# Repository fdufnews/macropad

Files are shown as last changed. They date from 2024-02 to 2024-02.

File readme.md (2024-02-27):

# MacroPad

## How it started from
As a left-hander, using keyboard shortcuts is usually problematic. Many of them have to use the left hand so I have to let go of the mouse, type the key combination, pick up the mouse again, or twist my fingers to type the key combination with the right hand.  
After some research on the Internet I found the [DuckyMacroPad](https://github.com/aarnas/pico-circuit-python/tree/main/Projects/DuckyMacroPad) of a simple combination of hardware and software. 

I quickly tested it and found some limitations to what I wanted. So I forked the repository and started my own version of Macropad. Added support for a matrix keyboard and some keywords to make the scripts more versatile.

## Description of what I wanted
- a macropad with between 9 and 12 keys (not too much keys as I wanted the keypad to stay atop my keyboard)
- progammed in Python
- no daemon on the computer
- support of different keymaps (I have a desktop with a french keyboard and a laptop with a US keyboard).
- programmable macros with support for some software and easy modification of them without a specific tool.

## What I ended with
 A macropad with:
 
- Raspberry Pi Pico, running CircuitPython (as CircuitPython supports USB HID and make the Pico be viewed as an externel disk)
- 12 buttons, 9 seems a bit limited
- 1 rotary encoder, this adds some pleasant tricks like undo/redo at the turn of a button
- a 280 x 240 TFT color display, to show key affectation

## Pin allocation on the Raspberry Pi Pico
```
|        |       |    |     ┏━━━━━┓     |    |          |          |
|        |       |    |┏━━━━┫     ┣━━━━┓|    |          |          |
|        | GP0   | 1  |┃◎   ┗━━━━━┛   ◎┃| 40 |VBUS      |          |
|        | GP1   | 2  |┃◎ ▩           ◎┃| 39 |VSYS      |          |
|        | Ground| 3  |┃▣ └─GP25      ▣┃| 38 |Ground    |          |
| L1     | GP2   | 4  |┃◎  ▒▒▒        ◎┃| 37 |3v3 En    |          |
| L2     | GP3   | 5  |┃◎  ▒▒▒        ◎┃| 36 |3v3 Out   |          |
| L3     | GP4   | 6  |┃◎             ◎┃| 35 |ADC VRef  |          |
| R1     | GP5   | 7  |┃◎             ◎┃| 34 |GP28 / A2 |          |
|        | Ground| 8  |┃▣             ▣┃| 33 |ADC Ground|          |
|        | GP6   | 9  |┃◎   ▓▓▓▓▓▓▓   ◎┃| 32 |GP27 / A1 |          |
| ROT1A  | GP7   | 10 |┃◎   ▓▓▓▓▓▓▓   ◎┃| 31 |GP26 / A0 |          |
| ROT1B  | GP8   | 11 |┃◎   ▓▓▓▓▓▓▓   ◎┃| 30 |run       |          |
| ROT1S  | GP9   | 12 |┃◎   ▓▓▓▓▓▓▓   ◎┃| 29 |GP22      | TFT_BLK  |
|        | Ground| 13 |┃▣             ▣┃| 28 |Ground    |          |
| C1     | GP10  | 14 |┃◎             ◎┃| 27 |GP21      | TFT_CS   |
| C2     | GP11  | 15 |┃◎             ◎┃| 26 |GP20      | TFT_MISO |
| C3     | GP12  | 16 |┃◎             ◎┃| 25 |GP19      | NU       |
| C4     | GP13  | 17 |┃◎             ◎┃| 24 |GP18      | TFT_SCK  |
|        | Ground| 18 |┃▣             ▣┃| 23 |Ground    |          |
| R2     | GP14  | 19 |┃◎             ◎┃| 22 |GP17      | TFT_CD   |
| R3     | GP15  | 20 |┃◎    ◎ ▣ ◎    ◎┃| 21 |GP16      | TFT_RS   |
|        |       |    |┗━━━━━━━━━━━━━━━┛|    |          |          |
```
R1-3 are reserved for future use. They are parts of the 2 connectors that are connecting the keyboard to the main board

The full [schematic is here](hardware/MacroPad.pdf)

## View of the Macropad
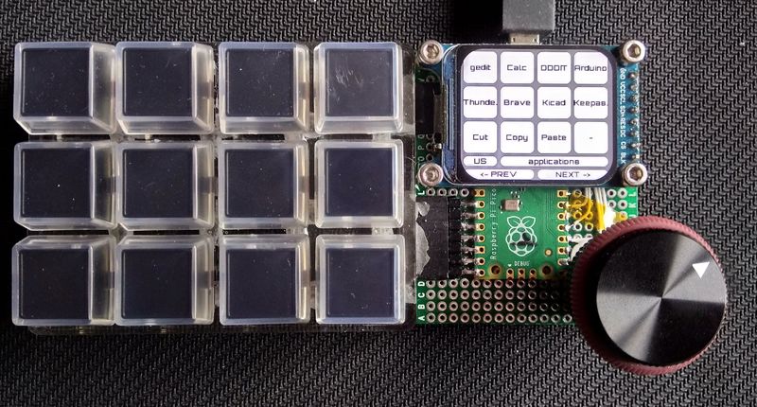
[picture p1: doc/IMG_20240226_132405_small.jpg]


## How it works
The Macropad embeds its own documentation.
If plugged with the rotary encoder pushed, the Macropad also shows itself as an external thumb drive where a readme.md with the documentation can be found.
It is [here too](software/pico_fs/readme.md)

## Software
The full source code with comments is [here](software/code_full.py)
The [pico_fs](pico_fs) directory contains all the necessary files to make a functionnal Macropad: a stripped code, the drivers, the fonts, some scripts.  
Once the Pico is programmed with CircuitPython, all files in pico_fs shall be copyed on the CIRCUITPY drive.

## Todo list
### Easy
[x] Add management of key colors in the settings.toml file  
[x] add a keyword for the script to switch the layer. Example, selecting Gedit in the *applications* layer launches Gedit and switches to *Edition* layer  
### Difficult
[] Look if it is possible to use either of icons or text in the keys without exploding memory and making software slower (Difficult as it can be very memory hungry).  
[] Search a way to place multi lines of text in the keys. It is very boring to be limited to 5 or 6 caracters (difficult as it all depends on the buttons library).

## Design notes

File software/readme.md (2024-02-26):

- code_full is the software with all the comments  
- stripcomments.sh is used to delete all the comments and generate a smaller file that is copied in pico_fs.  
- The content of pico_fs can be uploaded as is on the board. It contains a copy of the readme.md file so the Macropad embeds its own documentation

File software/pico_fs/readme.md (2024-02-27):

# MacroPad

## What it is
 A macropad with:
 
- a Raspberry Pi Pico, running CircuitPython (as CircuitPython supports USB HID and make the Pico be viewed as an externel disk)
- 12 buttons, 9 seems a bit limited
- 1 rotary encoder, this adds some pleasant tricks like undo/redo at the turn of a button
- a 280 x 240 TFT color display, to show key affectation

## View of the Macropad


## Detail of the display

```
╭───╮ ╭───╮ ╭───╮ ╭───╮
│ 0 │ │ 1 │ │ 2 │ │ 3 │ 
╰───╯ ╰───╯ ╰───╯ ╰───╯ 
╭───╮ ╭───╮ ╭───╮ ╭───╮
│ 4 │ │ 5 │ │ 6 │ │ 7 │ 
╰───╯ ╰───╯ ╰───╯ ╰───╯ 
╭───╮ ╭───╮ ╭───╮ ╭───╮
│ 8 │ │ 9 │ │ 10│ │ 11│ 
╰───╯ ╰───╯ ╰───╯ ╰───╯ 
LANG     Layer name
<- PREV         NEXT ->

```
| Item | Comment |
|:---|:---|
| 0..11 | The labels of the keys as extracted from the scripts|
| LANG | Displays the current selected language|
|Layer name | Shows the name of the current layer|
|PREV/NEXT | There is currently no way to dynamically change the labels for the rotary encoder.|

## Consumption
The Macropad consume 60mA with backlight at full power

## Syntax of the scripts
The scripts directory is where the script are saved.  
There is a directory for each layer which name is used as the layer's name that is displayed on the screen. Name can be any one supported by the filesystem. There is a scan of the scripts each time language is changed so if layers are added while the Macropad is running they can be recognized by simply switching the language.  
In each layer, there is one file for each key. 12 keys + rotary encoder CW and CCW fake buttons. Files are named 0 to 13.  
Scripts are using some keywords
### Keywords
#### Currently supported keywords
- `#` some text 
to add a comment.  
Ignored when playing the scripts
- LABEL xxxxxx  
Define the label that is printed on the key. SHALL BE THE 1rst LINE OF THE SCRIPT.  
Depending on the font's size, the label can be truncated if too long.  
If no LABEL is found on the first line of the script, the label will be the key number.  
Ignored when playing the scripts
- DELAY xxxx  
define a delay of xxxx mS
- STRING xxxxxxxx  
the string xxxxxxxx is sent to the host

- DEFAULT_DELAY or DEFAULTDELAY xxxx  
sets the default delay between keys when they are sent

- REPEAT xxx  
repeat the previous line xxx times

- KEY_SEL / KEY_UNSEL  
Set the key selected or not, when selected the color is inverted. Can be used for indication of the state of a latched key (see examples)

- FLAG_SET / FLAG_RESET xxxxx  
Set/reset flag named xxxx. Will be used with IF statements

- LAYER layerName  
switch the layer to layerName if it exists. Beware that a layer name is a directory name and can be case sensitive on some OS.

- IF / IF_NOT  xxxx  
Test if flag xxxx is set or not

- ELSE  
else statement, to be used with IF

- ENDIF  
close an IF or IF ... ELSE statement.

### Keycodes
Apart from the previous keywords a line can contain keycodes like
WINDOWS, GUI, APP, MENU, SHIFT, ALT, CONTROL, DOWNARROW, LEFTARROW, A, B, F1,....
So, to send ctrl+c one shall put `CONTROL C` on a single line
The list of the keywords can be find in the keycode libraries used

### Examples
#### Example 1
A macro to open gedit editor can be build like this
```text
LABEL Gedit
#  open launcher
ALT F2
#  wait for the popup to open
DELAY 200
#  GEDIT
STRING gedit
ENTER
```
#### Example 2
A macro to open the find dialog in gedit.  
When clicked for the first time: send CTRL+F to open the find dialog, sets the key as selected and sets a flag.  
If the flag is already set send escape to close the dialog, unselect the key, reset the flag. 
While the flag is set, it can be used to change the way the rotary encoder works and uses it to jump to next or previous words.    

```text
# Make a bistable key
IF_NOT CTRLF 
# open find dialog
CONTROL F
KEY_SEL
FLAG_SET CTRLF
ELSE
# close find dialog
ESC
KEY_UNSEL
FLAG_RESET CTRLF
ENDIF
```
Script for the CCW direction of the rotary encoder
```
LABEL NEXT ->
# if CTRLF active rotary encoder will send CTRL g (previous occurrence of word in search)
IF CTRLF
CONTROL SHIFT g
# if CTRLF not active will send CTRL z wich is undo
ELSE
CONTROL z
ENDIF
```
Keys are numbered from top left to bottom right

```
╭───╮ ╭───╮ ╭───╮ ╭───╮
│ 0 │ │ 1 │ │ 2 │ │ 3 │ 
╰───╯ ╰───╯ ╰───╯ ╰───╯ 
╭───╮ ╭───╮ ╭───╮ ╭───╮
│ 4 │ │ 5 │ │ 6 │ │ 7 │ 
╰───╯ ╰───╯ ╰───╯ ╰───╯      <--   -->
╭───╮ ╭───╮ ╭───╮ ╭───╮     ╭───╮ ╭───╮
│ 8 │ │ 9 │ │ 10│ │ 11│     │ 13│ │ 12│
╰───╯ ╰───╯ ╰───╯ ╰───╯     ╰───╯ ╰───╯
```
A macro can have any number of line. Beware, the longer the slower.  
A line can contain keywords and/or keycodes  

## Encoder pushbutton
A short push on the encoder pushbutton switches to the next layer. When reaching the last layer the count rolls back to 0.  
A long push switches the current language.

## Default configuration
The *settings.toml* file at the root of the file system can be used to specify the default language and layer.  
Settings are key pairs. One key name followed by an equal sign followed by the value in double quotes.  
Example  
```
lang="FR"
default="applications"
font="orbitron_black14.pcf"
style="ROUNDRECT"
background="ORANGE"
fill_color="0xffffff"
outline_color="GREEN"
label_color="DARKBLUE"
selected_fill="DARKGRAY"
selected_outline="RED"
selected_label="RED"
```

| key | Comment |
| :--- | :---|
|lang |Language for the keyboard either of "FR" or "US" others can be added in code.py|
|default |Layer opened by default, if missing the first layer, in alphabetical order, will be selected|
|font |Font used to display the label, if missing terminalio.FONT will be used. Fonts are supposed to be in the fonts directory. Only the filename is necessary, not a full path|
|style |Style of the buttons one of RECT, ROUNDRECT, SHADOWRECT, SHADOWROUNDRECT can not be used. If missing ROUNDRECT is used|
|background |Color of the background of the display. see color after the table|
|fill_color |Fill color of the buttons|
|outline_color |Color of the outline of the buttons|
|label_color |Color of the labels|
|selected_fill |Fill color when button is selected|
|selected_outline |Color of the outline of the buttons when selected|
|selected_label |Color of the labels when buttons are selected|

__color__: color can be a color name from the following list or an integer number either in decimal or in hexadecimal. Numbers shall be quoted too  
There is list of predefined colors in the code.  
BLACK = 0x000000  
LIGHTORANGE = 0xFF8800  
ORANGE = 0xe66100  
BROWN = 0x3F2200  
WHITE = 0xFFFFFF  
GRAY = 0x888888  
LIGHTGRAY = 0xdddddd  
DARKGRAY = 0x5e5c64  
LIGHTGREEN = 0x00FF44  
GREEN = 0x289525  
DARKGREEN = 0x19571d  
RED = 0xFF0000  
PURPLE = 0x9141ac  
YELLOW = 0xf8e45c  
LAVENDER = 0x99c1f1  
BLUE = 0x1c71d8  
DARKBLUE = 0x2e4480  
LIGHTBLUE = 0x62a0ea  

## USB drive
The Macropad can be viewed as an USB drive or not.  
By default, the USB drive mode is not active.  
To make this mode active, the user shall plug in the Macropad while keeping the rotary encoder pushed. The USB drive will then be active and the drive will be presented as CIRCUITPY. User can then modify, copy or edit any file. The drive is 1MB with around 150kB used by the default configuration so don't try to use it as a 'real thumb drive'.  

It is boot.py that tests if the rotary encoder is pushed at power on and activate or not the USB drive.
## Directory tree
Here is a picture of the directory tree on the CIRCUITPY disk.  
```text
root
     |
     |\_fonts
     |
     |\_lib
     |
     |\_scripts
     |         |
     |         |
     |         |\_layer0
     |         |        |\_0
     |         |        |\_1
     |         |        |\_..
     |         |        |\_12
     |         |        |\_13
     |         |
     |         |\_layer1
     |         |        |\_0
     |         |        |\_..
     |         |        |\_13
     |         |
     |
     |\_boot.py
     |\_code.py
     |\readme.md
     |\settings.toml
```

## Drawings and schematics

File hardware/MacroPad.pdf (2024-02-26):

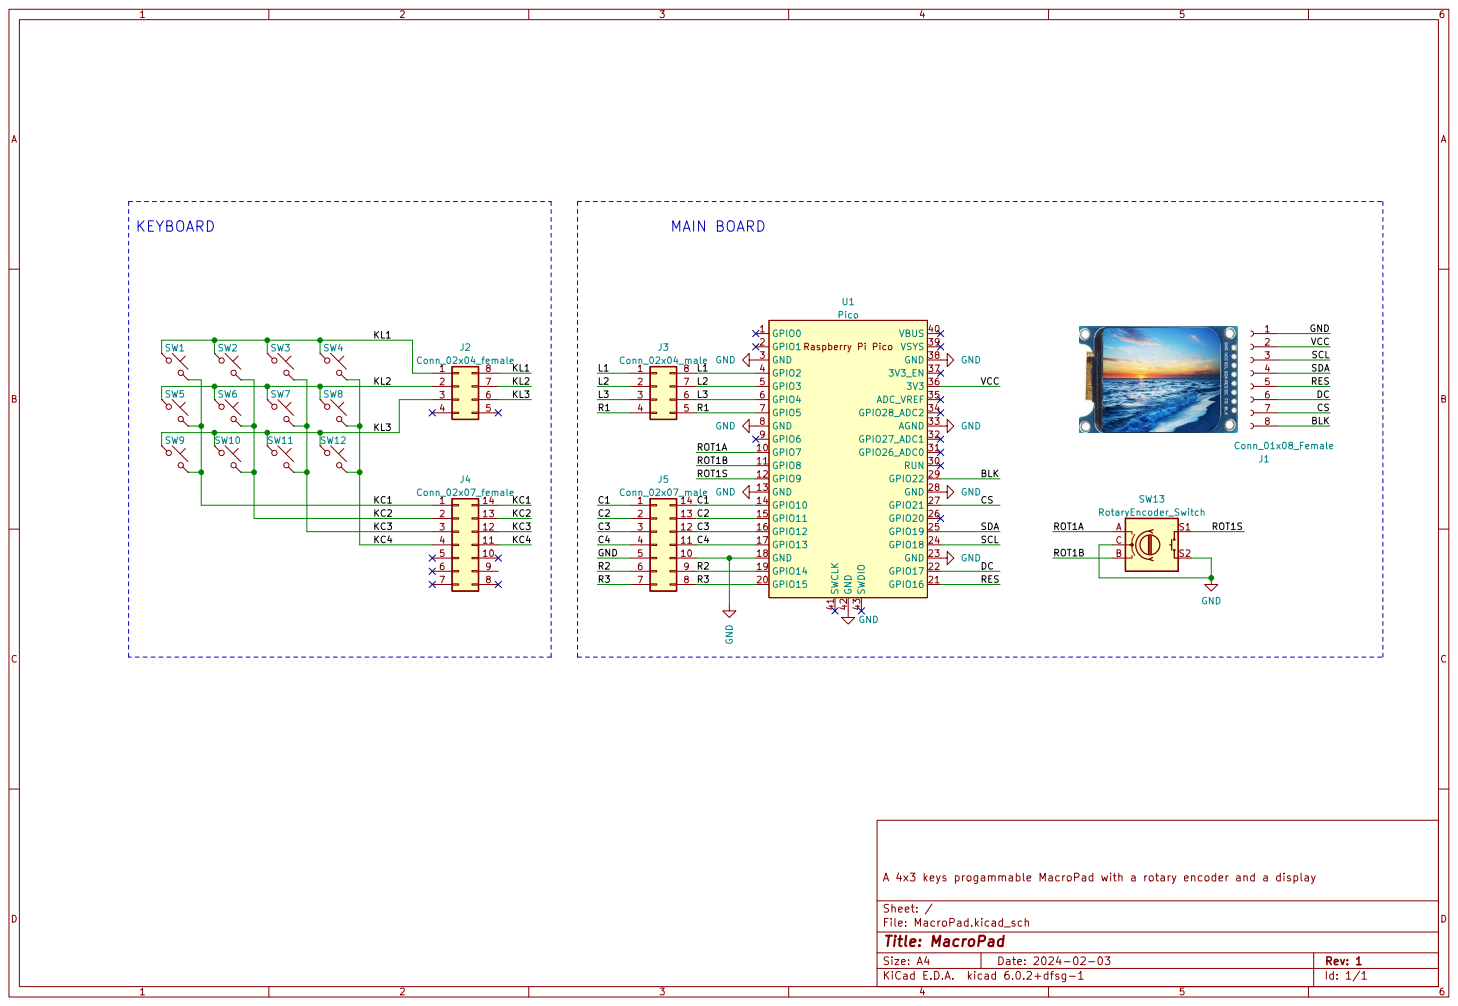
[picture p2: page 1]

File: MacroPad.kicad_sch Sheet: / A 4x3 keys progammable MacroPad with a rotary encoder and a display

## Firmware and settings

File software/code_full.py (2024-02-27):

import time
import board
import digitalio
import usb_hid
from adafruit_hid.keyboard import Keyboard
from adafruit_hid.keyboard_layout_us import KeyboardLayoutUS
from adafruit_hid.keycode import Keycode as KeycodeUS
from keyboard_layout_win_fr import KeyboardLayout as KeyboardLayoutFR
from keycode_win_fr import Keycode as KeycodeFR
import rotaryio
from fakeButton import *
import adafruit_matrixkeypad
import os

import busio
import terminalio
import displayio
from adafruit_display_text.label import Label
from adafruit_bitmap_font import bitmap_font
from adafruit_display_shapes.rect import Rect
from adafruit_button import Button
import gc

try:
    from fourwire import FourWire
except ImportError:
    from displayio import FourWire
from adafruit_st7789 import ST7789

version = '1.2'

tabLang = [['FR','US'],
            [KeyboardLayoutFR, KeyboardLayoutUS],
            [KeycodeFR, KeycodeUS]
]

langCount = len(tabLang[0])
langIndex = 0
language = ''
layerList = []
layerCount = 0
layerIndex = 0
layer = ''

labels = []

# declare a keyboard device with default FR layout
keyboard = Keyboard(usb_hid.devices)
layout = KeyboardLayoutFR(keyboard)
Keycode = KeycodeFR

# Extended 3x4 matrix keypad
cols = [digitalio.DigitalInOut(x) for x in (board.GP10, board.GP11, board.GP12, board.GP13)]
rows = [digitalio.DigitalInOut(x) for x in (board.GP2, board.GP3, board.GP4)]
# keys shall be numbered, starting from 0 and increasing 1 by 1, order is not important
keys = (
    (0, 1,  2,  3), 
    (4, 5,  6,  7), 
    (8, 9, 10, 11)
    )

keypad = adafruit_matrixkeypad.Matrix_Keypad(rows, cols, keys)

# compute size of keys array
nb_keys = len(keys) * len(keys[0])

# rotary encoder definition
encoder_A = board.GP7
encoder_B = board.GP8
encoder_PUSH = board.GP9
delayLongPush = 1000000000

# compute index of fake buttons using size of keys array so they are always registered after the key matrix 
coder_cw = nb_keys
coder_ccw = coder_cw + 1
# and add 2 elements to the length to manage rotary encoder CW and CCW
nb_keys += 2

# time for debounce keys in 10ms steps
time_debounce = 25

# dico containing the flags set in the scripts
dico_flags = {}
in_if = False
in_else = False
wait_else_or_endif = False
wait_endif = False

# Settings
BUTTON_WIDTH = 64
BUTTON_HEIGHT = 60
BUTTON_MARGIN = 4
STATUS_HEIGHT = 20

# Some colors
BLACK = 0x000000
LIGHTORANGE = 0xFF8800
ORANGE = 0xe66100
BROWN = 0x3F2200
WHITE = 0xFFFFFF
GRAY = 0x888888
LIGHTGRAY = 0xdddddd
DARKGRAY = 0x5e5c64
LIGHTGREEN = 0x00FF44
GREEN = 0x289525
DARKGREEN = 0x19571d
RED = 0xFF0000
PURPLE = 0x9141ac
YELLOW = 0xf8e45c
LAVENDER = 0x99c1f1
BLUE = 0x1c71d8
DARKBLUE = 0x2e4480
LIGHTBLUE = 0x62a0ea

style=Button.ROUNDRECT
background=GRAY
fill_col=WHITE
outline_col=BLACK
label_col=BLACK
sel_fill=BLACK
sel_outline=WHITE
sel_label=WHITE

font = terminalio.FONT

def button_grid(row, col):
    return(BUTTON_MARGIN * (row + 1) + BUTTON_WIDTH * row,
        BUTTON_MARGIN * (col + 1) + BUTTON_HEIGHT * col)

def add_button(col, row, label, width, fill_color, outline_color, label_color, selected_fill, selected_outline, selected_label, style):
    pos = button_grid(row, col)
    new_button = Button(x = pos[0], y = pos[1],
                    width=BUTTON_WIDTH * width + BUTTON_MARGIN * (width - 1),
                    height = BUTTON_HEIGHT, label=label, label_font=font,
                    label_color=label_color, fill_color=fill_color,
                    outline_color=outline_color, selected_fill=selected_fill,
                    selected_outline=selected_outline, selected_label=selected_label,
style=style)
    buttons.append(new_button)
    return new_button
    
def find_button(label):
    result = None
    for _, btn in enumerate(buttons):
        if btn.label == label:
            result = btn
    return result


def convertLine(line):
    newline = []
#    print(line)
    # loop on each key - the filter removes empty values
    for key in filter(None, line.split(" ")):
        key = key.upper()
        if hasattr(Keycode, key):
            # if it's in the Keycode module, use it (allows any valid keycode)
            newline.append(getattr(Keycode, key))
        else:
            # if it's not a known key name, show the error for diagnosis
#            print(f"Unknown key: <{key}>")
            pass
#    print(newline)
    return newline

def runScriptLine(line):
    for k in line:
        keyboard.press(k)
    keyboard.release_all()

def sendString(line):
    layout.write(line)

def switchKey(keynum, state):   
    buttons[keynum].selected = True if state == 'KEY_SEL' else False

def parseLine(filename, line):
    global defaultDelay
    global dico_flags
    global in_if
    global in_else
    global wait_else_or_endif
    global wait_endif
    global layerIndex
    global layer
    
# *******************************************************************
# Added keywords
# *******************************************************************
    if line[0:5] == "LABEL":
        # ignore LABEL statement
        pass
    elif(line[0:3] == "#"):
        # ignore script comments
        pass
    elif(line[0:5] == "LAYER"):
        param = line[5:].strip()
        if param in layerList:
            layer = param
            layerIndex = layerList.index(param)
            changeLayer(0)
    elif(line[0:6] == "IF_NOT"):
        flag = line[7:]
        # a flag missing in the dictonnary is considered False
        # maybe this will change later but it currently seems to be OK
        state = dico_flags.get(flag,False)
        if(not state):
            in_if = True
        else:
            wait_else_or_endif = True
    elif(line[0:2] == "IF"):
        flag = line[3:]
        # a flag missing in the dictonnary is considered False
        # maybe this will change later but it currently seems to be OK
        state = dico_flags.get(flag,False)
        if(state):
            in_if = True
        else:
            wait_else_or_endif = True
    elif(line[0:4] == "ELSE"):
        if( in_if):
            in_if = False
            wait_endif = True
        else:
            if(wait_else_or_endif):
                wait_else_or_endif = False
                in_else = True
#            else:
#                print("error ELSE without IF")
    elif(line[0:5] == "ENDIF"):
        if(in_if or in_else or wait_endif or wait_else_or_endif):
            in_if = False
            in_else = False
            wait_else_or_endif = False
            wait_endif = False
#        else:
#            print("error ENDIF without IF")
# *******************************************************************
    elif(not wait_else_or_endif and not wait_endif):
        if(line[0:5] == "DELAY"):
            time.sleep(float(line[6:])/1000)
        elif(line[0:6] == "STRING"):
            sendString(line[7:])
        elif(line[0:13] == "DEFAULT_DELAY"):
            defaultDelay = int(line[14:]) * 10
        elif(line[0:12] == "DEFAULTDELAY"):
            defaultDelay = int(line[13:]) * 10
        elif(line[0:7] == "KEY_SEL"):
            switchKey(int(filename), "KEY_SEL")
        elif(line[0:9] == "KEY_UNSEL"):
            switchKey(int(filename), "KEY_UNSEL")
        elif(line[0:8] == "SET_FLAG"):
            arg = line[9:]
            dico_flags[arg]=True
        elif(line[0:10] == "RESET_FLAG"):
            arg = line[11:]
            dico_flags[arg]=False
        else:
            newScriptLine = convertLine(line)
            runScriptLine(newScriptLine)

def runScript(filename):
    global in_if
    global in_else
    global wait_else_or_endif
    global wait_endif
    global language
    
    in_if = False
    in_else = False
    wait_else_or_endif = False
    wait_endif = False

    
    f = open(scriptsLib+'/'+filename,"r",encoding='utf-8')
    previousLine = ""
    script = f.readlines()
    for line in script:
        line = line.rstrip()
        if(line[0:6] == "REPEAT"):
            for i in range(int(line[7:])):
                #repeat the last command
                parseLine(filename, previousLine)
        else:
            parseLine(filename, line)
            previousLine = line

def listLang(langDir):
    global langList
    global langCount

    langList = os.listdir(langDir)
    langList.sort()
    langCount = len(langList)

def listLayer(dir):
    global layerList
    global layerCount
    
    layerList = os.listdir(dir)
    layerList.sort()
    layerCount = len(layerList)

def make_labels(path):
    global labels
    global nb_keys
    
    labels.clear()
    for i in range(nb_keys):
        labels.append(str(i))
    for filename in os.listdir(path):
        file = open(path + '/' + filename, 'r')
        line = file.readline()
        if line[0:5] == 'LABEL':
            label = line[6:].rstrip()
            labels[int(filename)] = label
        file.close()

def update_labels():
    for i, but in enumerate(buttons):
        but.label = labels[i]
        
    but_ccw.label = labels[nb_keys-1]
    but_cw.label = labels[nb_keys-2]
    
    stat_lang.label = language
    stat_mode.label = layer

def changeLayer(inc):
    global layerIndex
    global layerCount
    global layer
    global scriptsLib
    
    layerIndex = (layerIndex + inc) % layerCount
    layer = layerList[layerIndex]
    scriptsLib = '/scripts/'+layer
    
    make_labels(scriptsLib)
    update_labels()

def changeLanguage():
    global langList
    global langCount
    global langIndex
    global language
    global layout
    global Keycode
    global layerIndex
    global layer
    
    langIndex = (langIndex + 1) % langCount

    language = tabLang[0][langIndex]
    KeyboardLayout = tabLang[1][langIndex]
    Keycode = tabLang[2][langIndex]
        
    layout = KeyboardLayout(keyboard)
    listLayer('/scripts/')
    layerIndex = 0
    changeLayer(0)

def managePush():
    timePushed = time.monotonic_ns()
    elapsedTime = 0
    time.sleep(0.05)
    while not encoderPush.value and (elapsedTime < delayLongPush): # wait for button released or timeout
        elapsedTime = time.monotonic_ns() - timePushed
        time.sleep(0.01)
    if (elapsedTime > delayLongPush): # if timeout
        changeLanguage()
        while not encoderPush.value:
            time.sleep(0.01)
    else:
        changeLayer(1)   

def getDefaultStyle():
    global font
    global style
    global background
    global fill_col
    global outline_col
    global label_col
    global sel_fill
    global sel_outline
    global sel_label

    temp = os.getenv('font',None)
    font = font if temp == None else eval("bitmap_font.load_font('/fonts/" + temp +"')")
    temp = os.getenv('style',None)
    style = style if temp == None else eval('Button.'+temp)
    temp = os.getenv('background',None)
    background = background if temp == None else eval(temp)
    temp = os.getenv('fill_color',None)
    fill_col = fill_col if temp == None else eval(temp)
    temp = os.getenv('outline_color',None)
    outline_col = outline_col if temp == None else eval(temp)
    temp = os.getenv('label_color',None)
    label_col = label_col if temp == None else eval(temp)
    temp = os.getenv('selected_fill',None)
    sel_fill = sel_fill if temp == None else eval(temp)
    temp = os.getenv('selected_outline',None)
    sel_outline = sel_outline if temp == None else eval(temp)
    temp = os.getenv('selected_label',None)
    sel_label = sel_label if temp == None else eval(temp)

def getDefault():
    global language
    global langIndex
    global layer
    global layerIndex

    language = os.getenv('lang',None)
    layer = os.getenv('layer',None)

    listLang('/scripts')
    if (language == None) or (not (language in tabLang[0])):
        language = tabLang[0][0]
    langIndex = tabLang[0].index(language)
    listLayer('/scripts/')
    if (layer == None) or (not (layer in layerList)):
        layer = layerList[0]
    layerIndex = layerList.index(layer)
    changeLayer(0)

# ************************************************************************

       
# add 2 fake buttons linked to the rotary encoder rotation
enc = rotaryio.IncrementalEncoder(encoder_A, encoder_B)
cw = fakeButton(enc, fakeButton.CW, fakeButton.ACTIVE_LOW )
ccw = fakeButton(enc, fakeButton.CCW, fakeButton.ACTIVE_LOW)

# add encoder's push button
encoderPush = digitalio.DigitalInOut(encoder_PUSH)
encoderPush.direction = digitalio.Direction.INPUT
encoderPush.pull = digitalio.Pull.UP

# Create last pressed buttons list
last_pressed = [0 for _ in range(nb_keys)]
pressed = []

# Release any resources currently in use for the displays
displayio.release_displays()

# initialize display I/Os
spi_clk = board.GP18
spi_mosi = board.GP19
tft_cs = board.GP21
tft_dc = board.GP17
tft_res= board.GP16
tft_blk = board.GP22
blk = digitalio.DigitalInOut(tft_blk)
blk.direction = digitalio.Direction.OUTPUT
blk.value=1

spi = busio.SPI(spi_clk, spi_mosi)

display_bus = FourWire(spi, command=tft_dc, chip_select=tft_cs, reset=tft_res, baudrate=64000000)

display = ST7789(display_bus, width=280, height=240, rowstart=20, rotation=90)

# scan scripts directory
getDefaultStyle()


# Make the display context
root = displayio.Group()
display.root_group = root

# Make a background color fill
color_bitmap = displayio.Bitmap(280, 240, 1)
color_palette = displayio.Palette(1)
color_palette[0] = background
bg_sprite = displayio.TileGrid(color_bitmap, pixel_shader=color_palette, x=0, y=0)
root.append(bg_sprite)

buttons = []

add_button(0, 0, '0', 1, fill_col, outline_col, label_col, sel_fill, sel_outline, sel_label, style)
add_button(0, 1, '1', 1, fill_col, outline_col, label_col, sel_fill, sel_outline, sel_label, style)
add_button(0, 2, '2', 1, fill_col, outline_col, label_col, sel_fill, sel_outline, sel_label, style)
add_button(0, 3, '3', 1, fill_col, outline_col, label_col, sel_fill, sel_outline, sel_label, style)
add_button(1, 0, '4', 1, fill_col, outline_col, label_col, sel_fill, sel_outline, sel_label, style)
add_button(1, 1, '5', 1, fill_col, outline_col, label_col, sel_fill, sel_outline, sel_label, style)
add_button(1, 2, '6', 1, fill_col, outline_col, label_col, sel_fill, sel_outline, sel_label, style)
add_button(1, 3, '7', 1, fill_col, outline_col, label_col, sel_fill, sel_outline, sel_label, style)
add_button(2, 0, '8', 1, fill_col, outline_col, label_col, sel_fill, sel_outline, sel_label, style)
add_button(2, 1, '9', 1, fill_col, outline_col, label_col, sel_fill, sel_outline, sel_label, style)
add_button(2, 2, '10', 1, fill_col, outline_col, label_col, sel_fill, sel_outline, sel_label, style)
add_button(2, 3, '11', 1, fill_col, outline_col, label_col, sel_fill, sel_outline, sel_label, style)

for b in buttons:
    root.append(b)

# add a status line
ystatus = 4 * BUTTON_MARGIN + 3 * BUTTON_HEIGHT

stat_lang = Button(x = BUTTON_MARGIN, y = ystatus,
                    width = BUTTON_WIDTH,
                    height = STATUS_HEIGHT, label="FR", label_font=font,
                    label_color=label_col, fill_color=fill_col,outline_color=outline_col,
style=style)
root.append(stat_lang)

stat_mode = Button(x = 2 * BUTTON_MARGIN + BUTTON_WIDTH, y = ystatus,
                    width =  2 * BUTTON_MARGIN + 3 * BUTTON_WIDTH,
                    height = STATUS_HEIGHT, label="Editor", label_font=font,
                    label_color=label_col, fill_color=fill_col,outline_color=outline_col,
style=style)
root.append(stat_mode)

ystatus += STATUS_HEIGHT + BUTTON_MARGIN

but_ccw = Button(x = BUTTON_MARGIN, y = ystatus,
                    width = BUTTON_MARGIN + 2 * BUTTON_WIDTH,
                    height = STATUS_HEIGHT, label="<-- prev", label_font=font,
                    label_color=label_col, fill_color=fill_col,outline_color=outline_col,
style=style)
root.append(but_ccw)

but_cw = Button(x =  3 * BUTTON_MARGIN + 2 * BUTTON_WIDTH, y = ystatus,
                    width = BUTTON_MARGIN + 2 * BUTTON_WIDTH,
                    height = STATUS_HEIGHT, label="next -->", label_font=font,
                    label_color=label_col, fill_color=fill_col,outline_color=outline_col,
style=style)
root.append(but_cw)

# scan scripts directory
getDefault()

gc.collect()

while True:
    # read keymatrix
    pressedKey = keypad.pressed_keys
    
    # add rotary encoder's state
    if not cw.value:
        pressedKey.append(coder_cw)
    if not ccw.value:
        pressedKey.append(coder_ccw)
    # read rotary encoder's push button 
    if not encoderPush.value:
        time.sleep(0.01)
        managePush()
        
###################################################
    for ix in range(nb_keys):
        if ix in pressedKey:
            last_pressed[ix] = time_debounce if last_pressed[ix] <= 1 else last_pressed[ix]
    
    for ix, lp in enumerate(last_pressed):
        if lp == time_debounce:
            if ix not in pressed:
                pressed.append(ix)
                runScript(str(ix))

    for ix, lp in enumerate(last_pressed):
        if lp == 1 and ix in pressed:
                pressed.remove(ix)

    last_pressed = [max(0, lp - 1) for lp in last_pressed]

    time.sleep(0.01)

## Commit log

2024-02-26 1rst file commit
    First upload of the files to the repo
    [MacroPad.kicad_sch]
2024-02-27 Added more settings in settings.toml
    - added shappe and colors of the buttons in settings.toml
    - added font in settings.toml
    - updated readme.md
2024-02-27 Added a key word to change layer from inside a script, refactored readme
    - addition of the LAYER keyword in order to change layers from inside a
    script
    - Instead of duplicating the readme.md at the root of the repo and in
    the pico_fs, the readme was cut in two, generic at the repository root
    and syntax oriented in pico_fs.
